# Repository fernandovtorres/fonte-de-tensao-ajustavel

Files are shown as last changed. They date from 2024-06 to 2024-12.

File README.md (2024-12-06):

# Fonte de tensão ajustável

*Projeto para a disciplina Eletronica para Computação - SSC0180*

# Integrantes do Grupo

- Nicholas Eiti Dan - 14600749
- João Gabriel Araújo de Bastos - 15462633
- Matheus Vieira Fernandes - 14615993
- Fernando Valentim Torres - 15452340

# Sobre o Projeto

Neste trabalho, projetamos uma fonte de tensão regulável 3v a 12v. Para isso, utilizamos a voltagem alternada de 127v 60hz vinda da tomada e transformamos em voltagem contínua utilizando um transformador e um circuito retificador feito com diodos.

# Tabela dos componentes
| Componente | Quantidade | Custo por unidade |
|---|---|---|
|Transformador 24.2v |1 |emprestado|
| Resistor 100 ohms, 2 watts|  2 |  1.70 |
| Transistor NPN | 4 |  1.55 |
| Resistor 100 ohms, 0.25 watt | 6 |  0.08 |
| Capacitor 840 µF | 1 |  5.20 |
| Diodos (ponte retificadora) | 4 |  0.20 |
| Zener 13V | 1 |  0.50 |
| Zener 3.9V (queda de 2.4V) | 1 |  0.37 |
| Potenciômetro 10 kOhms | 1 |  7.00 |
| LED vermelho | 1 |  0.50 |
| Protoboard 830 pontos | 2 | 12.26 |
| Jumpers | 27 |  0.70 |
|Resistor 4.7k ohms |2 |  0.58 |  
|Resistor 2.2k ohms |1 |  0.60 |
|Resistor 3.3k ohms |1 |  0.39 |
|Resistor 1k ohms |1 |  0.59 |
|Resistor 10k ohms |1 |  0.46 |
|----- | **`TOTAL: 57`** | **`Preço Total: R$ 32,68`** |

# Informações sobre os componentes
- **transformador**: tem o papel de reduzir a voltagem de 127v vinda de uma fonte de corrente alternada (a tomada) para 24.2v, ainda alternada.
- **ponte de diodo**: a ponte de diodo é um arranjo de 4 diodos dispostos de uma forma com que a corrente alternada se tranforme em contínua
- **capacitor**: armazena carga no circuito durante os ciclos, liberando corrente quando a tensão provinda da fonte for menor do que a tensão interna do capacitor. Com base em um cálculo de 4% de ripple, chegamos próximos ao valor comercial de 820uF
- **diodo zener**: quando a voltagem passa de 13v, ele mantém esse valor como máximo em seus terminais, porém quando a voltagem é menor do que 13v, ele não conduz, logo não interfere
- **potenciômetro**: é um resistor regulável que será usado como o controle da tensão final.
- **transistor**: amplifica a corrente com base na resistência do potenciometro.
- **resistores**: utilizado em diversoss momentos no circuito, possui a função de limitar a corrente, o que garante uma certa segurança para os outros componentes do circuito.
- **led**: tem como função indicar quando a voltagem atingir 5 volts na parte final do circuito. de modo geral, não interfere nos valores obtidos no circuito, servindo unicamente como indicação da voltagem e corrente ajustáveis.

# Cálculos

### Antes do transformador:

$$ \ V_{\text{tomada}} = 127\ V \quad \Rightarrow \quad V_{\text{pico da tomada}} = 127 \cdot \sqrt{2} \approx 179,6\ V \ $$

### Após o transformador:

$$ \ V_0\ \text{pico} \approx 179,6 \cdot 0,1533 \approx 26,1\ V \ $$

### Depois da ponte retificadora:

$$ \ V_1\ \text{pico} \approx 26,1 - 2,6 \approx 23,5\ V \ $$

### Buscando a capacitância mínima para um ripple de no máximo 10%:

$$ \ R_{\text{eq}} \approx 230Ω \ $$

$$\ V_{\text{ripple}} = \frac{V_{\text{cc}}}{f \cdot C \cdot R_{\text{eq}}} \quad \Rightarrow \quad 2,35 \geq \frac{V_1\ \text{pico}}{120 \cdot C \cdot R_{\text{eq}}} \ $$

$$ \ \quad 2,35 \geq \frac{23,5}{120 \cdot C \cdot 230} \ $$

$$ \ C \geq \frac{23,5}{120 \cdot 2,35 \cdot 230} \approx 362\ \mu F \ $$

### Com um capacitor de 820µF, é possível obter um ripple de:

$$ \ \frac{10^6}{120 \cdot 820 \cdot 230} \approx 4\\% \ $$

# Imagem do Falstad

Screenshot from 2024-06-29 16-26-51

[Link para o falstad](https://tinyurl.com/2gezskvp)

# PCB no Eagle

Board
  
# Esquemático no Eagle

schematic

# Foto do Projeto



# Vídeos

https://github.com/fernandovtorres/fonte-de-tensao-ajustavel/assets/54219097/06e4c6fe-193a-48ef-a1b3-73d7a6c7bd2a

[Video Explicativo](https://youtu.be/Dz2hcll39sc)

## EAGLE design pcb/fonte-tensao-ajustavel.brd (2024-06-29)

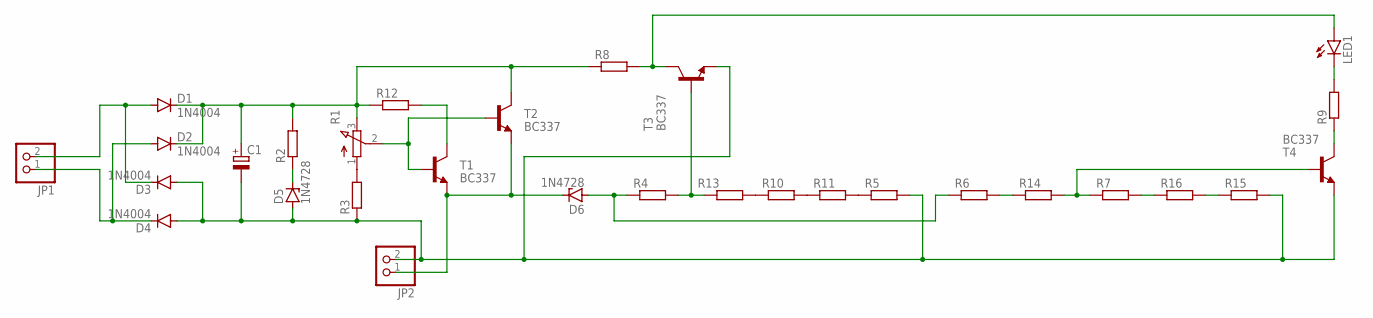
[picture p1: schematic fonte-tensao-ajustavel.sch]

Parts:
C1: CPOL-EUE5-10.5; E5-10,5
D1, D2, D3, D4: 1N4004; DO41-10
D5, D6: 1N4728; DO41Z10
JP1, JP2: PINHD-1X2; 1X02
LED1: LED5MM
R1: 3RP/1610N
R2, R3, R4, R5, R6, R7, R8, R9, R10, R11, R13, R14, R15, R16: R-EU_0204/7; 0204/7
R12: R-EU_0414/15; 0414/15
T1, T2, T3, T4: BC337; TO92

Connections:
unnamed: D1.A, D3.C, JP1.2
unnamed: D2.A, D4.C, JP1.1
unnamed: R5.1, R11.2
unnamed: C1.-, D3.A, D4.A, D5.A, JP2.2, R3.1, R5.2, R15.2, T3.1 (E), T4.1 (E)
unnamed: D5.C, R2.1
unnamed: R1.1 (A), R3.2
unnamed: D6.C, JP2.1, T1.1 (E), T2.1 (E)
unnamed: R1.2 (S), T1.2 (B), T2.2 (B)
unnamed: C1.+, D1.C, D2.C, R1.3 (E), R2.2, R8.1, R12.1, T2.3 (C)
unnamed: D6.A, R4.1, R6.1
unnamed: R4.2, R13.1, T3.2 (B)
unnamed: R7.1, R14.2, T4.2 (B)
unnamed: LED1.K (C), R9.2
unnamed: R9.1, T4.3 (C)
unnamed: LED1.A, R8.2, T3.3 (C)
unnamed: R12.2, T1.3 (C)
unnamed: R10.2, R11.1
unnamed: R10.1, R13.2
unnamed: R6.2, R14.1
unnamed: R7.2, R16.1
unnamed: R15.1, R16.2

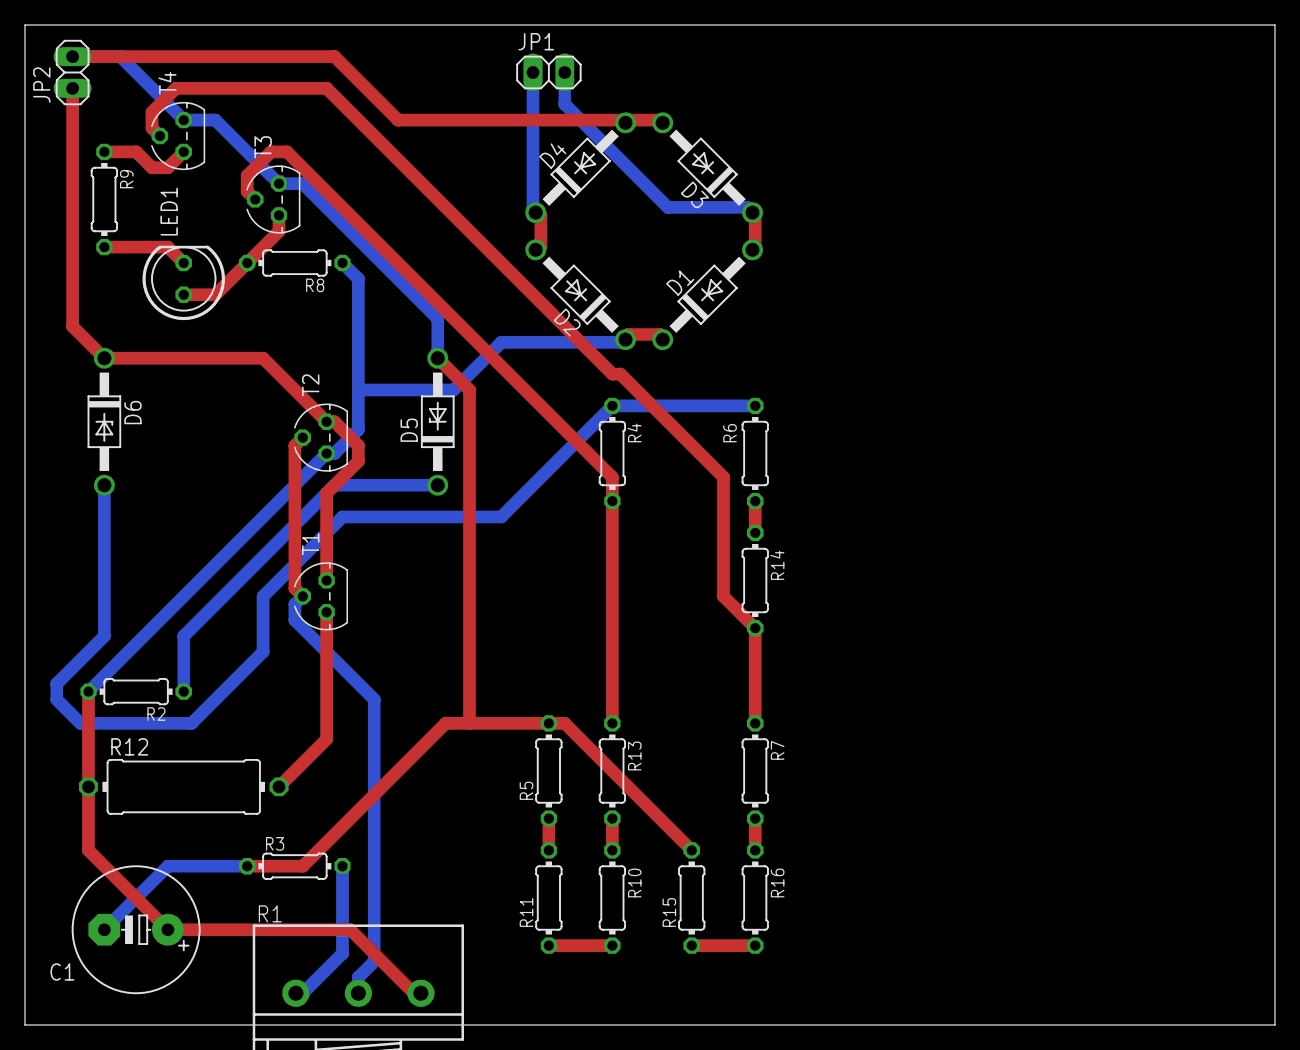
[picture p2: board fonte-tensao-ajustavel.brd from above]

Board: 2 copper layers, 100.0 x 80.0 mm, 30 parts (0 on the bottom side), 21 nets.

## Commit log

2024-06-29 Adicionar arquivos da PCB criados no Eagle
    [fonte-tensao-ajustavel.brd, fonte-tensao-ajustavel.sch]
2024-12-06 só que não sei o que
